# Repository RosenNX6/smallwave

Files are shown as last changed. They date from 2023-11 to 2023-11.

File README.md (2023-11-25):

# smallwave

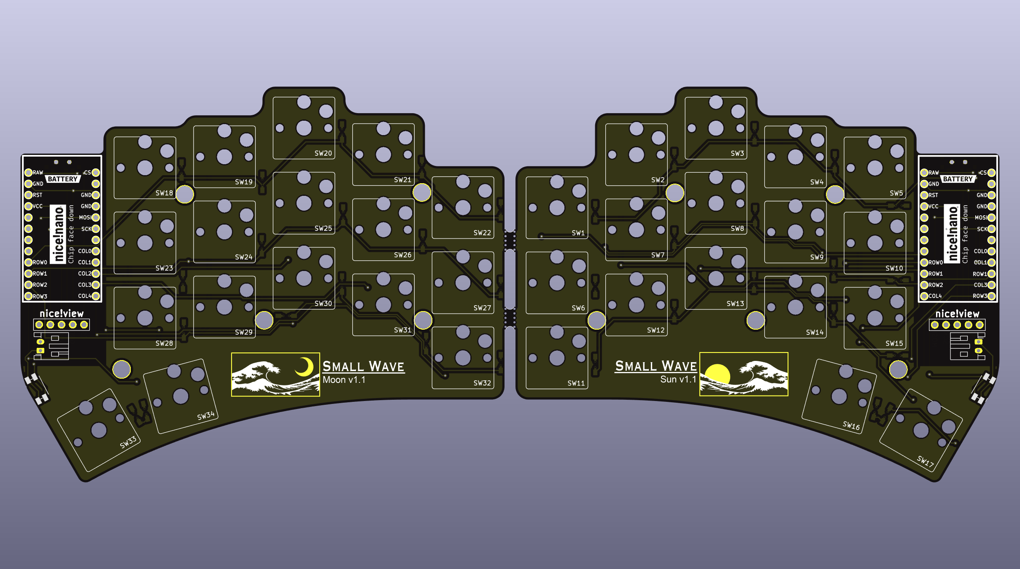
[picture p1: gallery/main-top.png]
PCB Preview


<span>
  
  
  
  
</span>

The smallwave is a 34 key wireless split keyboard with a e-paper style display.
This design ultimately comes from the popular [Sweep](https://github.com/davidphilipbarr/Sweep) layout but was built by modifying the [Urchin](https://github.com/duckyb/uchin) design and inspired by many aspects of the [Flipper](https://github.com/benvallack/the-flipper) and Corne layout.

## Hardware List
#### Required Parts
- 1× smallwave PCB (files can be found in the gerbers folder)
- 2× nice!nano
- 2× Lipo battery
- 48× Mill-max machined pins
- 2× Pair of female headers
- 34× Kailh choc hotswap sockets
- 34× Kailh choc v1 switches
- 34× Keycaps
- 34× SMD diodes

#### Optional Parts
- 2x nice!view
- 12x Vinyl self adhesive pads
- 2x Magnetic type C cable
- 1x Dual port USB wall charger

#### Itemized Parts Receipt (v1.0 build)
| Quantity | Item | Source | Cost |
| :---: | --- | --- | --- |
| 2 | nice!nano | typeractive.xyz | $50.00 |
| 2 | nice!view | typeractive.xyz | $40.00 |
| 40 | SMD Diode | typeractive.xyz | $3.00 |
| 40 | Kailh Hotswap Sockets | typeractive.xyz | $6.00 |
| 40 | Kailh Low Profile Choc Switches (Pro Red) | typeractive.xyz | $28.00 |
| 4 | MBK Choc Keycaps (1u convex) | typeractive.xyz | $2.00 |
| 2 | MBK Choc Keycaps (1u homing) | typeractive.xyz | $1.00 |
| 30 | MBK Choc Keycaps (1u) | typeractive.xyz | $10.50 |
| 4 | Machine Sockets and Pins | typeractive.xyz | $13.00 |
| 2 | Reset Button | typeractive.xyz | $1.50 |
| 2 | Battery Jack (black) | typeractive.xyz | $2.00 |
| 2 | Power Switch | typeractive.zyz | $1.50 |
| 2 | Lithium Battery 110mAh (BLK PH 2.0mm) | typeractive.xyz | $8.00 |
| 5 | smallwave PCB | jlcpcb.com | $38.93 |
| 16 | Vinyl Self Adhesive Pads (round 3/8") | Ace Hardware | $4.99 |
| 2 | Magnetic Type C Cable | amazon.com | $14.99 |
| 1 | Anker PowerPort Mini Dual Port USB Wall Charger | amazon.com | $6.99 |

## Design Software
#### KiCad
PCB design, part locations, copper traces, and pads. This was a steep learning curve for me but the software was incredible once I got the hang of it.
#### AutoCAD
PCB shape (edge cuts). This can be done in KiCad but I am inexperienced with the software and felt much more comfortable drawing prototype shapes in a software I am more familiar with.
#### Inkscape
Used for making the PCB art through the use of SVG files. 
#### Github
Used for programming the keyboard in the ZMK language directly in the web browser. How cool is that? More on this below.

## Firmware
The smallwave utilizes the ZMK programming language. To view, download, or edit the zmk programming used for this project, visit the [zmk-config-smallwave repository](https://github.com/rosennx6/zmk-config-smallwave).

## Inspiration/Credits
This build was inspired by the Ferris Sweep, Ben Vallack's Flipper, and Duccio's Urchin. I started this project with zero knowledge of keyboards, PCBs, or programming but, along with browsing [r/ErgoMechKeyboards](https://www.reddit.com/r/ErgoMechKeyboards/) the videos below were very helpful for me in getting started.
- [You Won't Beleive How Effective This Keyboard Layout Is](https://youtu.be/8wZ8FRwOzhU?si=EpPOE7a2gVTnpphz)
- [A Tiny, Ultra-Affordable Keyboard You Can Build Yourself!](https://youtu.be/JqpBKuEVinw?si=qibRUbN7NvYlW7R7)
- [How to make a SWEEP KEYBOARD (beginner friendly!)](https://youtu.be/fBPu7AyDtkM?si=BP1d7TfXiWL5cw6Q)
- [URCHIN Ergonomic Keyboard Build](https://youtu.be/CHSh1-dJq24?si=E14KtWMmz5-_V5mR)
- [PCB Art - A Step By Step Tutorial](https://youtu.be/vD6es-Y4LLc?si=0AxjCWdZhJgSs7d_)
- [Beginner ZMK Tutorial - How to make and modify your ZMK keymap](https://youtu.be/Kx8F4xI5yno?si=BYquHvFE0kq7FGJF)
- [How to Set Up ZMK Firmware From Scratch](https://youtu.be/O_urj-rF3bQ?si=-QcN1Bxoi7COPyYP)

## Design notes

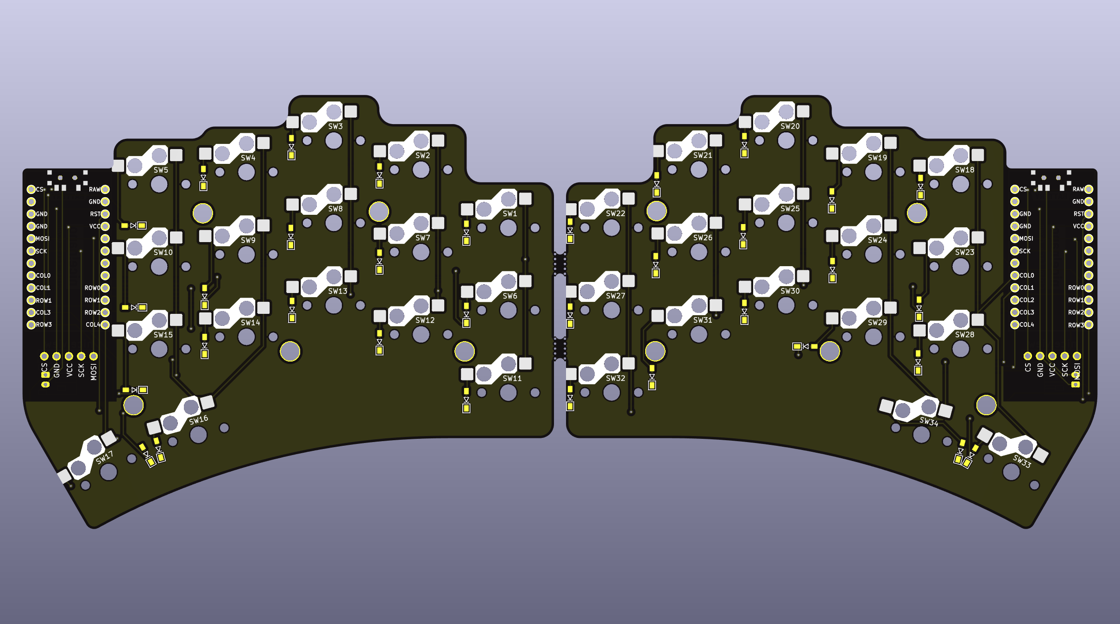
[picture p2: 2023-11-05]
gallery/main-bottom.png

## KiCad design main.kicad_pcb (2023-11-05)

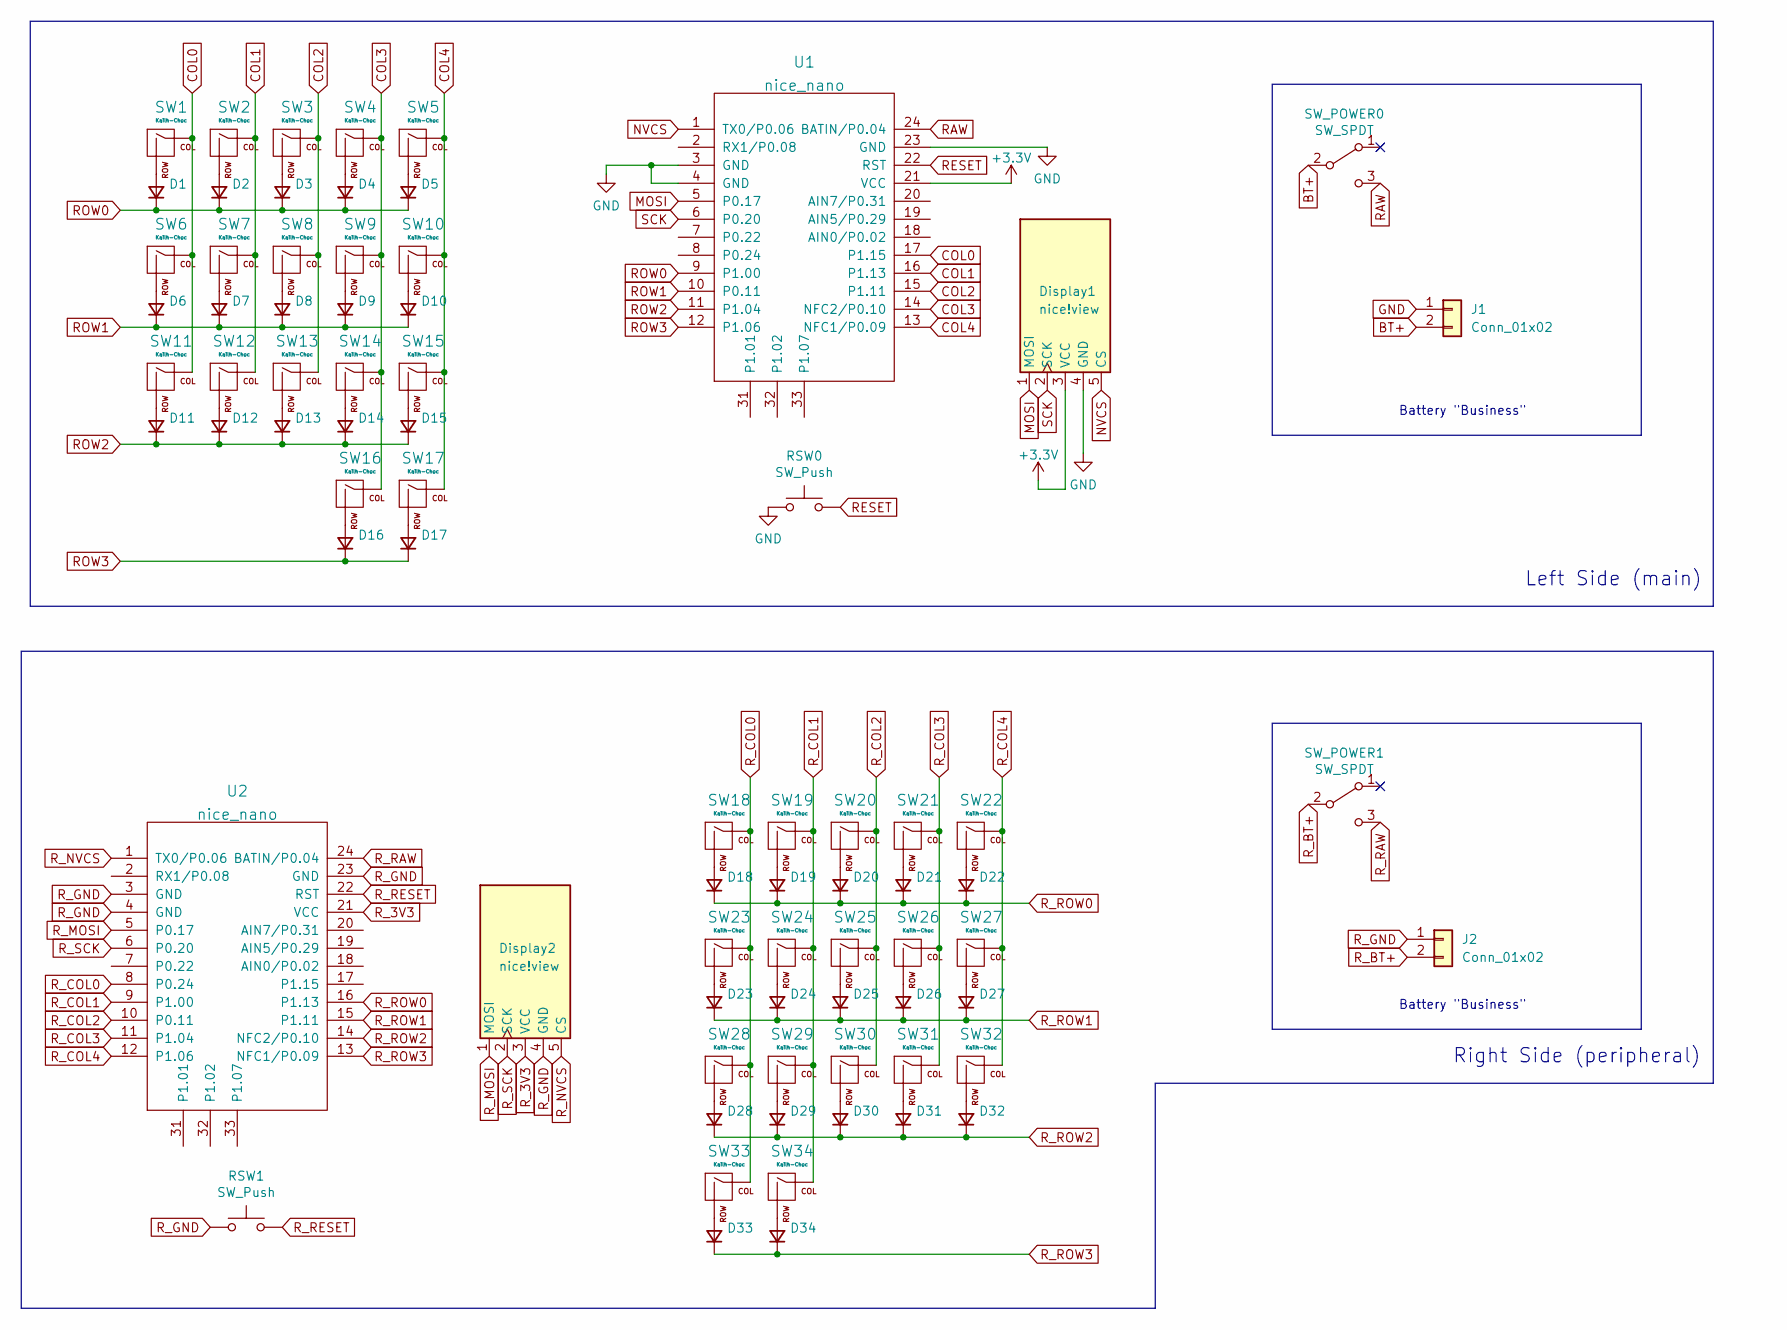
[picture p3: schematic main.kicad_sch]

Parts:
D1, D2, D3, D4, D5, D6, D7, D8, D9, D10, D11, D12, D13, D14, D15, D16, D17, D18, D19, D20, D21, D22, D23, D24, D25, D26, D27, D28, D29, D30, D31, D32, D33, D34: diode; SMD_Diode_Tiny
Display1, Display2: nice!view; nice_view
J1, J2: Conn_01x02; JST_PH_S2B-PH-K_1x02_P2.00mm_Horizontal
RSW0, RSW1: SW_Push; SW_RESET
SW1, SW2, SW3, SW4, SW5, SW6, SW7, SW8, SW9, SW10, SW11, SW12, SW13, SW14, SW15, SW16, SW17, SW18, SW19, SW20, SW21, SW22, SW23, SW24, SW25, SW26, SW27, SW28, SW29, SW30, SW31, SW32, SW33, SW34: Kailh-Choc; SW_Hotswap_Kailh_Choc_V1_tweaked
SW_POWER0, SW_POWER1: SW_SPDT; smt-slider-switch
U1, U2: nice_nano

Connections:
+3V3: Display1.3 (VCC), U1.21 (VCC)
BT+: J1.2, SW_POWER0.2 (B)
COL0: SW1.1 (COL), SW6.1 (COL), SW11.1 (COL), U1.17 (P1.15)
COL1: SW2.1 (COL), SW7.1 (COL), SW12.1 (COL), U1.16 (P1.13)
COL2: SW3.1 (COL), SW8.1 (COL), SW13.1 (COL), U1.15 (P1.11)
COL3: SW4.1 (COL), SW9.1 (COL), SW14.1 (COL), SW16.1 (COL), U1.14 (NFC2/P0.10)
COL4: SW5.1 (COL), SW10.1 (COL), SW15.1 (COL), SW17.1 (COL), U1.13 (NFC1/P0.09)
GND: Display1.4 (GND), J1.1, RSW0.1, U1.3 (GND), U1.4 (GND), U1.23 (GND)
MOSI: Display1.1 (MOSI), U1.5 (P0.17)
NVCS: Display1.5 (CS), U1.1 (TX0/P0.06)
unnamed: D1.2 (A), SW1.2 (ROW)
unnamed: D2.2 (A), SW2.2 (ROW)
unnamed: D3.2 (A), SW3.2 (ROW)
unnamed: D4.2 (A), SW4.2 (ROW)
unnamed: D5.2 (A), SW5.2 (ROW)
unnamed: D6.2 (A), SW6.2 (ROW)
unnamed: D7.2 (A), SW7.2 (ROW)
unnamed: D8.2 (A), SW8.2 (ROW)
unnamed: D9.2 (A), SW9.2 (ROW)
unnamed: D10.2 (A), SW10.2 (ROW)
unnamed: D11.2 (A), SW11.2 (ROW)
unnamed: D12.2 (A), SW12.2 (ROW)
unnamed: D13.2 (A), SW13.2 (ROW)
unnamed: D14.2 (A), SW14.2 (ROW)
unnamed: D15.2 (A), SW15.2 (ROW)
unnamed: D16.2 (A), SW16.2 (ROW)
unnamed: D17.2 (A), SW17.2 (ROW)
unnamed: D18.2 (A), SW18.2 (ROW)
unnamed: D19.2 (A), SW19.2 (ROW)
unnamed: D20.2 (A), SW20.2 (ROW)
unnamed: D21.2 (A), SW21.2 (ROW)
unnamed: D22.2 (A), SW22.2 (ROW)
unnamed: D23.2 (A), SW23.2 (ROW)
unnamed: D24.2 (A), SW24.2 (ROW)
unnamed: D25.2 (A), SW25.2 (ROW)
unnamed: D26.2 (A), SW26.2 (ROW)
unnamed: D27.2 (A), SW27.2 (ROW)
unnamed: D28.2 (A), SW28.2 (ROW)
unnamed: D29.2 (A), SW29.2 (ROW)
unnamed: D30.2 (A), SW30.2 (ROW)
unnamed: D31.2 (A), SW31.2 (ROW)
unnamed: D32.2 (A), SW32.2 (ROW)
unnamed: D33.2 (A), SW33.2 (ROW)
unnamed: D34.2 (A), SW34.2 (ROW)
RAW: SW_POWER0.3 (C), U1.24 (BATIN/P0.04)
RESET: RSW0.2, U1.22 (RST)
ROW0: D1.1 (K), D2.1 (K), D3.1 (K), D4.1 (K), D5.1 (K), U1.9 (P1.00)
ROW1: D6.1 (K), D7.1 (K), D8.1 (K), D9.1 (K), D10.1 (K), U1.10 (P0.11)
ROW2: D11.1 (K), D12.1 (K), D13.1 (K), D14.1 (K), D15.1 (K), U1.11 (P1.04)
ROW3: D16.1 (K), D17.1 (K), U1.12 (P1.06)
R_3V3: Display2.3 (VCC), U2.21 (VCC)
R_BT+: J2.2, SW_POWER1.2 (B)
R_COL0: SW18.1 (COL), SW23.1 (COL), SW28.1 (COL), SW33.1 (COL), U2.8 (P0.24)
R_COL1: SW19.1 (COL), SW24.1 (COL), SW29.1 (COL), SW34.1 (COL), U2.9 (P1.00)
R_COL2: SW20.1 (COL), SW25.1 (COL), SW30.1 (COL), U2.10 (P0.11)
R_COL3: SW21.1 (COL), SW26.1 (COL), SW31.1 (COL), U2.11 (P1.04)
R_COL4: SW22.1 (COL), SW27.1 (COL), SW32.1 (COL), U2.12 (P1.06)
R_GND: Display2.4 (GND), J2.1, RSW1.1, U2.3 (GND), U2.4 (GND), U2.23 (GND)
R_MOSI: Display2.1 (MOSI), U2.5 (P0.17)
R_NVCS: Display2.5 (CS), U2.1 (TX0/P0.06)
R_RAW: SW_POWER1.3 (C), U2.24 (BATIN/P0.04)
R_RESET: RSW1.2, U2.22 (RST)
R_ROW0: D18.1 (K), D19.1 (K), D20.1 (K), D21.1 (K), D22.1 (K), U2.16 (P1.13)
R_ROW1: D23.1 (K), D24.1 (K), D25.1 (K), D26.1 (K), D27.1 (K), U2.15 (P1.11)
R_ROW2: D28.1 (K), D29.1 (K), D30.1 (K), D31.1 (K), D32.1 (K), U2.14 (NFC2/P0.10)
R_ROW3: D33.1 (K), D34.1 (K), U2.13 (NFC1/P0.09)
R_SCK: Display2.2 (SCK), U2.6 (P0.20)
SCK: Display1.2 (SCK), U1.6 (P0.20)

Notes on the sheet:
Right Side (peripheral)
Battery "Business"
Left Side (main)

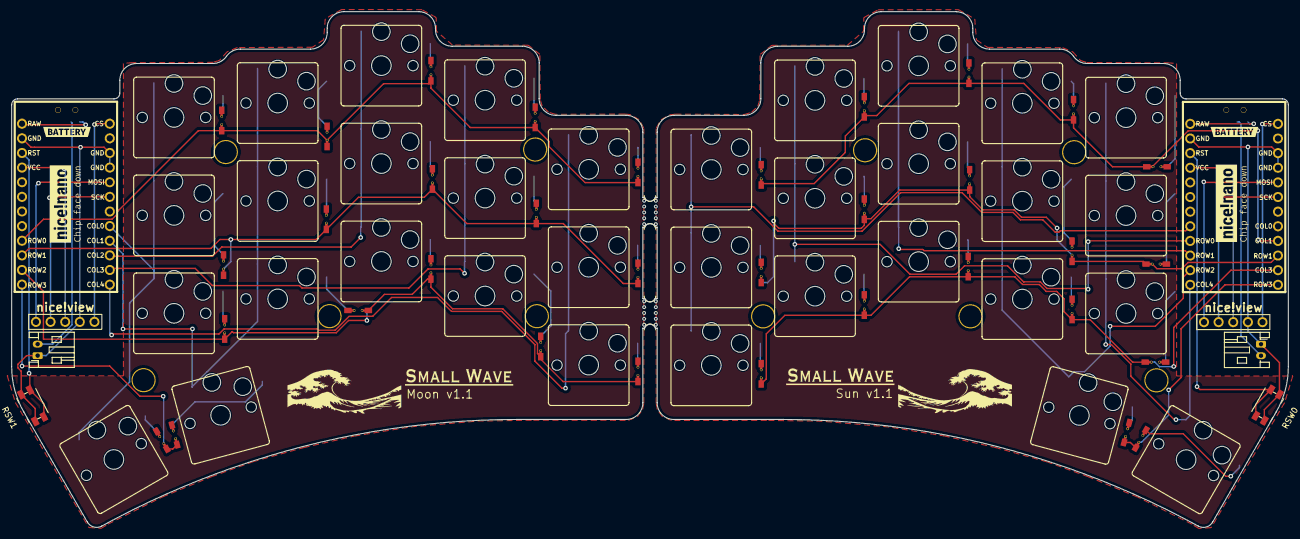
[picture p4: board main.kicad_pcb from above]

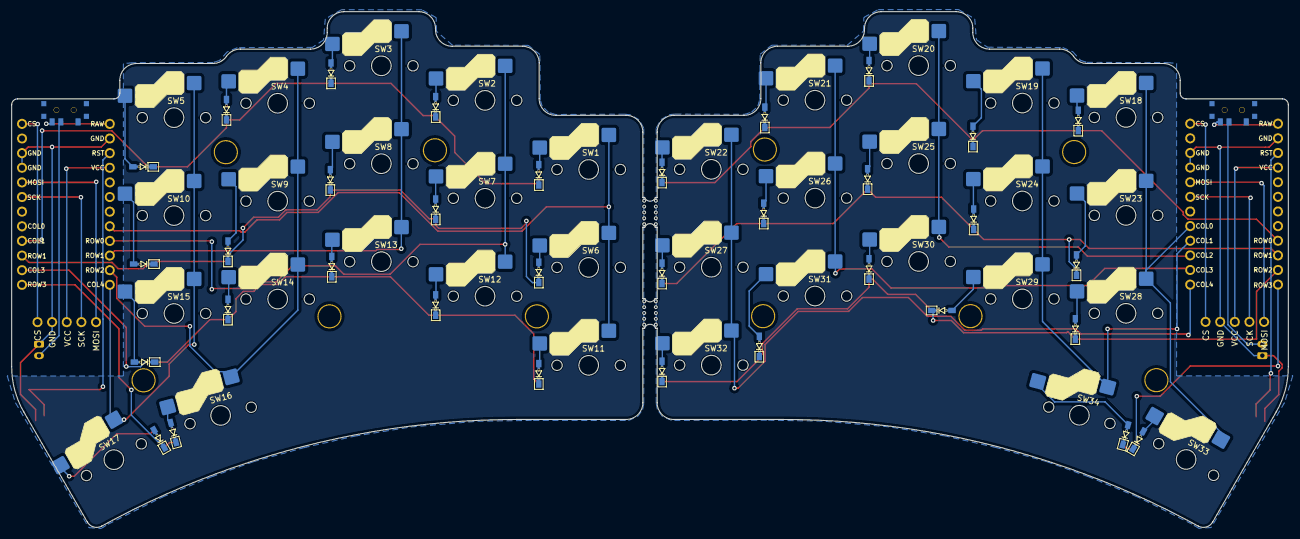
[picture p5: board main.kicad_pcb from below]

Board: 2 copper layers, 221.6 x 89.5 mm, 96 parts (9 on the bottom side), 68 nets.

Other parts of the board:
H1, H1#2, H2, H2#2, H3, H3#2, H4, H4#2, H4#3, H4#4: M2 Hole; M2_hole_4.2mm
kibuzzard-636588C8, kibuzzard-636588C8#2: G***; kibuzzard-636588C8
kibuzzard-636592CC: G***; kibuzzard-636592CC
kibuzzard-6365884B: G***; kibuzzard-6365884B
kibuzzard-63658865: G***; kibuzzard-63658865
kibuzzard-63659296: G***; kibuzzard-63659296
mouse-bite-2mm-slot, mouse-bite-2mm-slot#2: VAL**; mouse-bite-5mm-slot-with-space-for-track

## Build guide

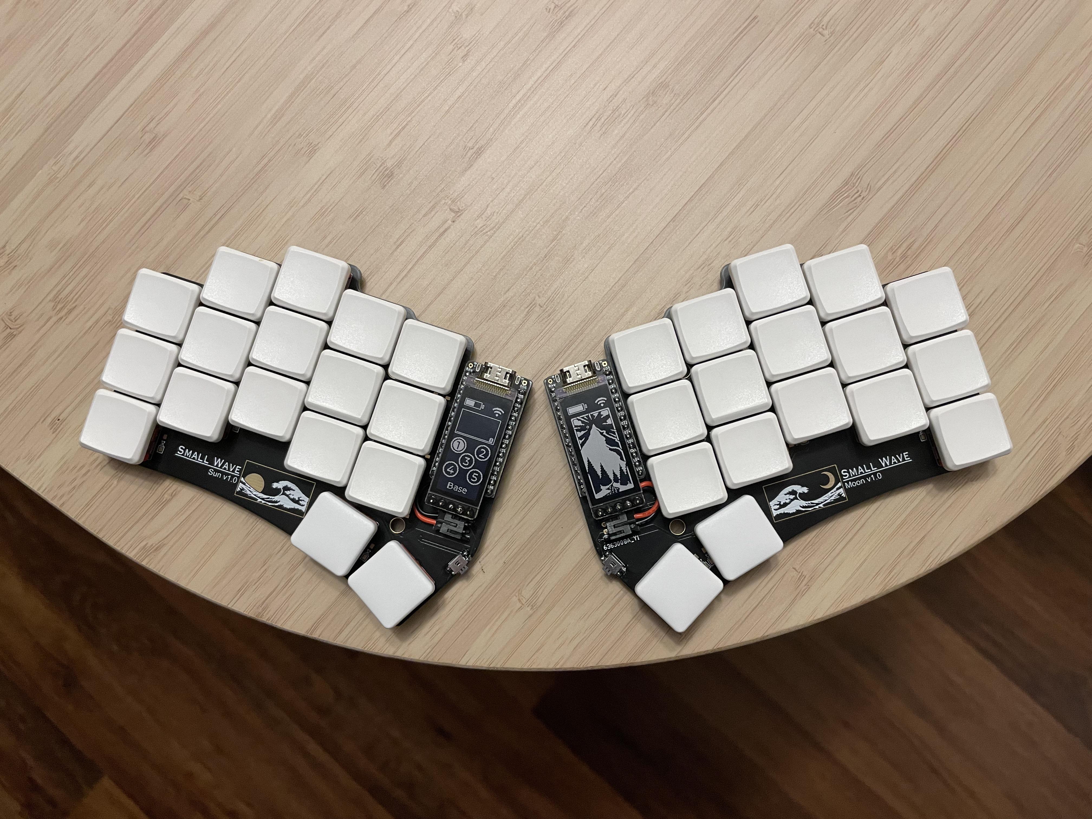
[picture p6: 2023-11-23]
gallery/v1.0 finished build.jpg
